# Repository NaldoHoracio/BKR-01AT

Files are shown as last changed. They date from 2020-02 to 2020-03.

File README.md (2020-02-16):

# Projeto Final da Disciplina de Circuitos Impressos
## BKR-01AT

"Eu gostaria que fosse desenvolvido um equipamento que fosse capaz de medir as vibrações e a temperatura de um gerador em funcionamento. Vou chamá-lo de BKR:01AT. Acredito que, a partir dos dados obtidos, poderemos tirar algumas conclusões que podem aumentar o tempo de vida útil do equipamento. O equipamento deve enviar as leituras para uma central a qual já está pronta se comunica com os sensores em uma rede mesh."

Os equipamentos selecionados para desenvolver esse equipamento são:
- Acelerômetro: LIS2DHTR;
- MCU + Bluetooth: nRF52832-QFAB;
- LED indicativo de sistema ligado (livre escolha, cor verde)
- LED indicativo de problema de vibração detectado (livre escolha, cor vermelha)
- LED indicativo de problema de temperatura detectado (livre escolha, cor vermelha)
- Botão de reset (livre escolha, baixo custo)
- Botão de função 1 (livre escolha, baixo custo)
- Botão de função 2 (livre escolha, baixo custo)
- Alimentação por bateria CR2032 de 3,0V (não precisa comprar, mas precisa ter os furos para soldar a pilha)
- Outros componentes necessários são de livre escolha inclusive a antena;

Restrições:
1. A placa deve ter componentes de apenas um lado;
2. A logomarca da empresa deve aparecer na camada Silk na parte de baixo da placa (onde não tem componentes)
3. A placa tem que ter o formato quadrado nas dimensões 60x60mm
4. A placa deve ter furos de montagem nas quinas superior esquerda e inferior direito com diâmetro de 3,2mm e o centro do furo deve estar a 5mm das duas bordas;
5. A placa será montada por equipamentos automáticos portanto deve conter dois fiduciais posicionados na maior distância possível entre eles na placa;
6. O nome do projeto deve estar presente na parte frontal da placa acompanhado com a versão P1;
7. As bordas a placa devem ser arredondadas;
8. O resistores utilizados devem ser 0402;
9. O equipamento deve ter interface de gravação TC2030;
10. As trilhas de alimentação devem ter 12mil de espessuras e as de sinal 6mil;
11. O Clearence da placa deve ser de 6mil;
12. A trilha da antena deve ser calculada utilizando coplanar wave guide para obter uma impedância de 50 ohms;
13. A trilha deve ser protegida com um shielding por todo o seu comprimento e deve ser cercada por um plano de ground com stitching aplicado a ele.

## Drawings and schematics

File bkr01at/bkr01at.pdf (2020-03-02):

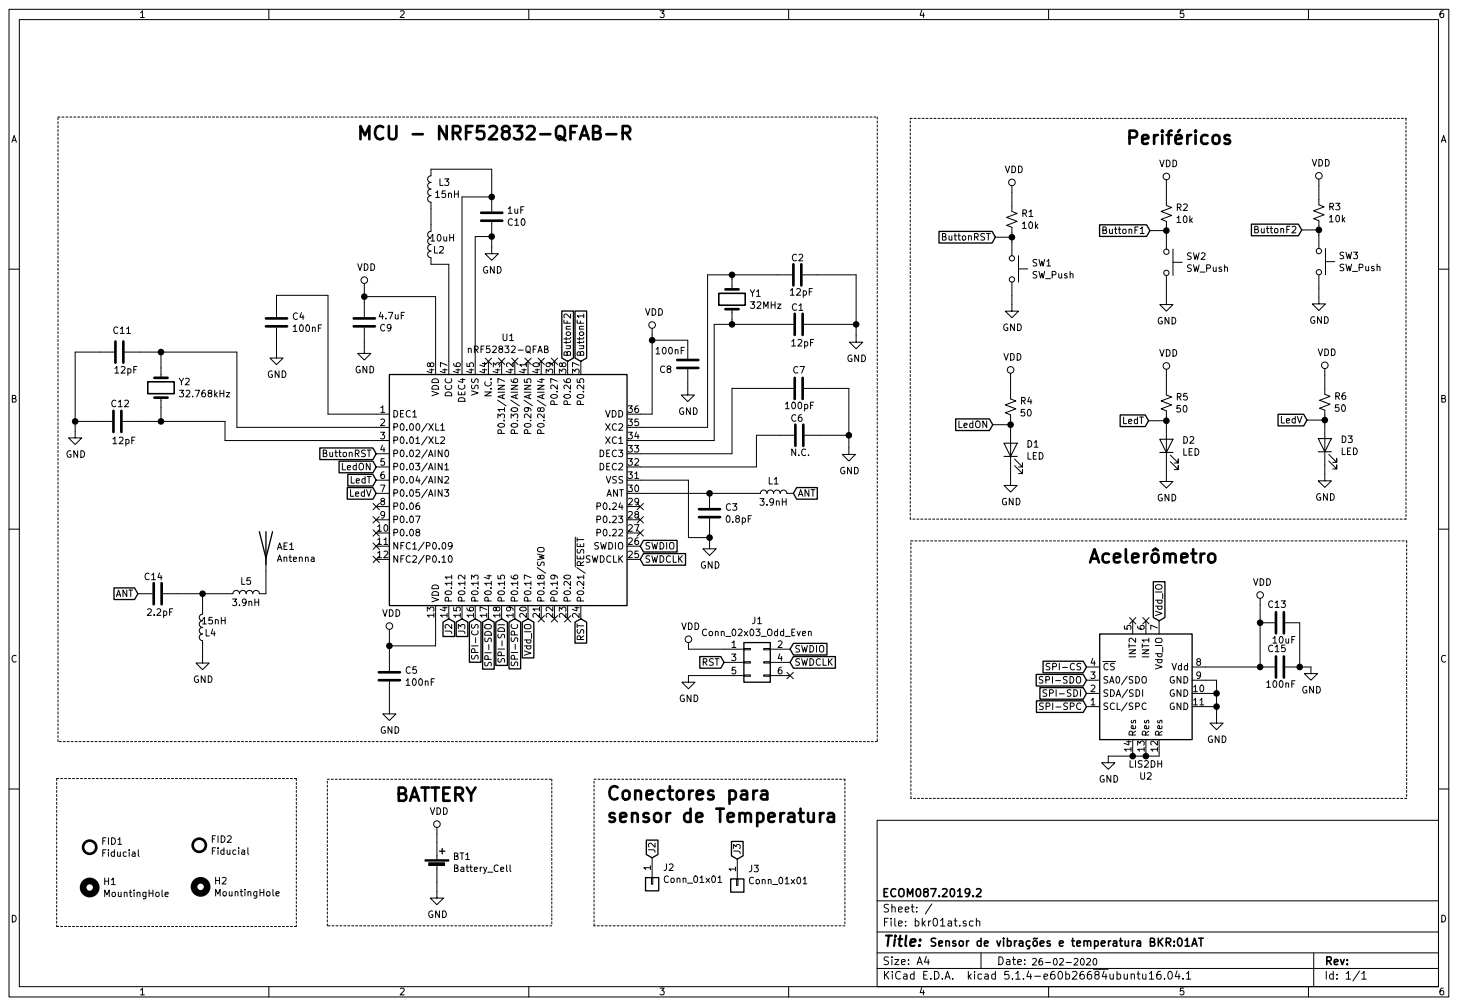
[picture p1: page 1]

SPI-SDI SPI-SDO

ECOM087.2019.2
Id: 1/1 Title: File: bkr01at.sch Sheet: /

Sensor de vibrações e temperatura BKR:01AT

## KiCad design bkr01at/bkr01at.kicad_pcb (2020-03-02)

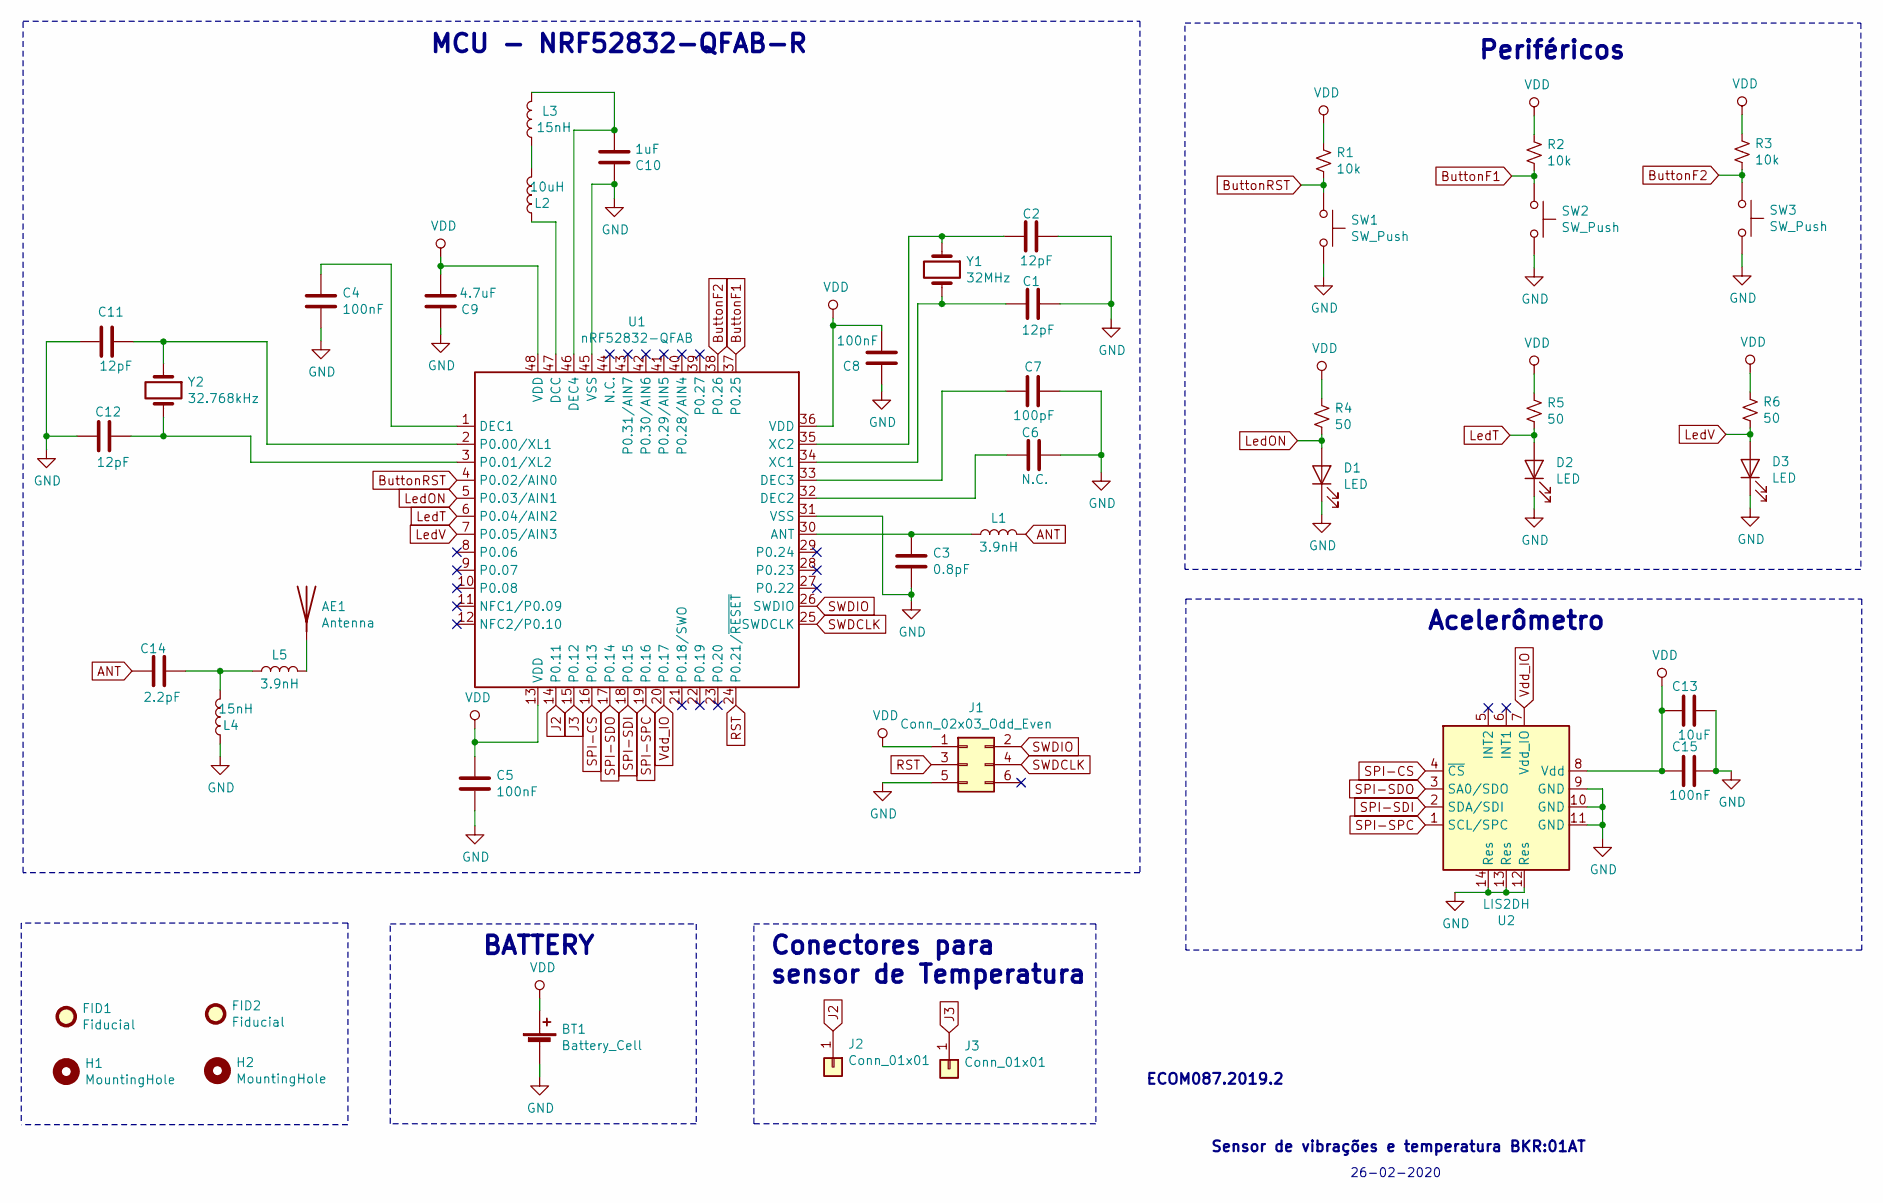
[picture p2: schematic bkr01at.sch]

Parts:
AE1: Antenna; 2450AT18B100
BT1: Battery_Cell; Battery_Panasonic_CR2032-VS1N_Vertical_CircularHoles
C1, C2, C11, C12: 12pF; C_0402_1005Metric
C3: 0.8pF; C_0402_1005Metric
C4, C5, C8, C15: 100nF; C_0402_1005Metric
C6: N.C.; C_0402_1005Metric
C7: 100pF; C_0402_1005Metric
C9: 4.7uF; C_0402_1005Metric
C10: 1uF; C_0402_1005Metric
C13: 10uF; C_0402_1005Metric
C14: 2.2pF; C_0402_1005Metric
D1, D2, D3: LED; LED_0603_1608Metric
FID1, FID2: Fiducial; Fiducial_0.5mm_Mask1.5mm
H1, H2: MountingHole; MountingHole_3.2mm_M3
J1: Conn_02x03_Odd_Even; Tag-Connect_TC2030-IDC-NL_2x03_P1.27mm_Vertical
J2, J3: Conn_01x01; SolderWirePad_1x01_Drill0.8mm
L1, L5: 3.9nH; L_0402_1005Metric
L2: 10uH; L_0402_1005Metric
L3, L4: 15nH; L_0402_1005Metric
R1, R2, R3: 10k; R_0402_1005Metric
R4, R5, R6: 50; R_0402_1005Metric
SW1, SW2, SW3: SW_Push; SW_MEC_5GSH9
U1: nRF52832-QFAB; QFN-48-1EP_6x6mm_P0.4mm_EP4.6x4.6mm
U2: LIS2DH; LGA-14_2x2mm_P0.35mm_LayoutBorder3x4y
Y1: 32MHz; Crystal_SMD_2016-4Pin_2.0x1.6mm
Y2: 32.768kHz; Crystal_SMD_3215-2Pin_3.2x1.5mm

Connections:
ANT: C14.1, L1.2
ButtonF1: R2.2, SW2.1, U1.37 (P0.25)
ButtonF2: R3.2, SW3.1, U1.38 (P0.26)
ButtonRST: R1.2, SW1.1, U1.4 (P0.02/AIN0)
GND: BT1.2 (-), C1.2, C2.2, C3.2, C4.2, C5.2, C6.2, C7.2, C8.1, C9.1, C10.1, C11.2, C12.2, C13.2, C15.2, D1.1 (K), D2.1 (K), D3.1 (K), J1.5, L4.1, SW1.2, SW2.2, SW3.2, U1.31 (VSS), U1.45 (VSS), U2.9 (GND), U2.10 (GND), U2.11 (GND), U2.12 (Res), U2.13 (Res), U2.14 (Res)
J2: J2.1, U1.14 (P0.11)
J3: J3.1, U1.15 (P0.12)
LedON: D1.2 (A), R4.2, U1.5 (P0.03/AIN1)
LedT: D2.2 (A), R5.2, U1.6 (P0.04/AIN2)
LedV: D3.2 (A), R6.2, U1.7 (P0.05/AIN3)
unnamed: AE1.1, L5.2
unnamed: C1.1, U1.34 (XC1), Y1.2
unnamed: C2.1, U1.35 (XC2), Y1.1
unnamed: C3.1, L1.1, U1.30 (ANT)
unnamed: C4.1, U1.1 (DEC1)
unnamed: C6.1, U1.32 (DEC2)
unnamed: C7.1, U1.33 (DEC3)
unnamed: C10.2, L3.2, U1.46 (DEC4)
unnamed: C11.1, U1.2 (P0.00/XL1), Y2.1
unnamed: C12.1, U1.3 (P0.01/XL2), Y2.2
unnamed: C14.2, L4.2, L5.1
unnamed: L2.1, U1.47 (DCC)
unnamed: L2.2, L3.1
RST: J1.3, U1.24 (P0.21/~RESET)
SPI-CS: U1.16 (P0.13), U2.4 (~CS)
SPI-SDI: U1.18 (P0.15), U2.2 (SDA/SDI)
SPI-SDO: U1.17 (P0.14), U2.3 (SA0/SDO)
SPI-SPC: U1.19 (P0.16), U2.1 (SCL/SPC)
SWDCLK: J1.4, U1.25 (SWDCLK)
SWDIO: J1.2, U1.26 (SWDIO)
VDD: BT1.1 (+), C5.1, C8.2, C9.2, C13.1, C15.1, J1.1, R1.1, R2.1, R3.1, R4.1, R5.1, R6.1, U1.13 (VDD), U1.36 (VDD), U1.48 (VDD), U2.8 (Vdd)
Vdd_IO: U1.20 (P0.17), U2.7 (Vdd_IO)

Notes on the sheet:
Sensor de vibrações e temperatura BKR:01AT
ECOM087.2019.2
26-02-2020
MCU - NRF52832-QFAB-R
Periféricos
Acelerômetro
BATTERY
Conectores para sensor de Temperatura

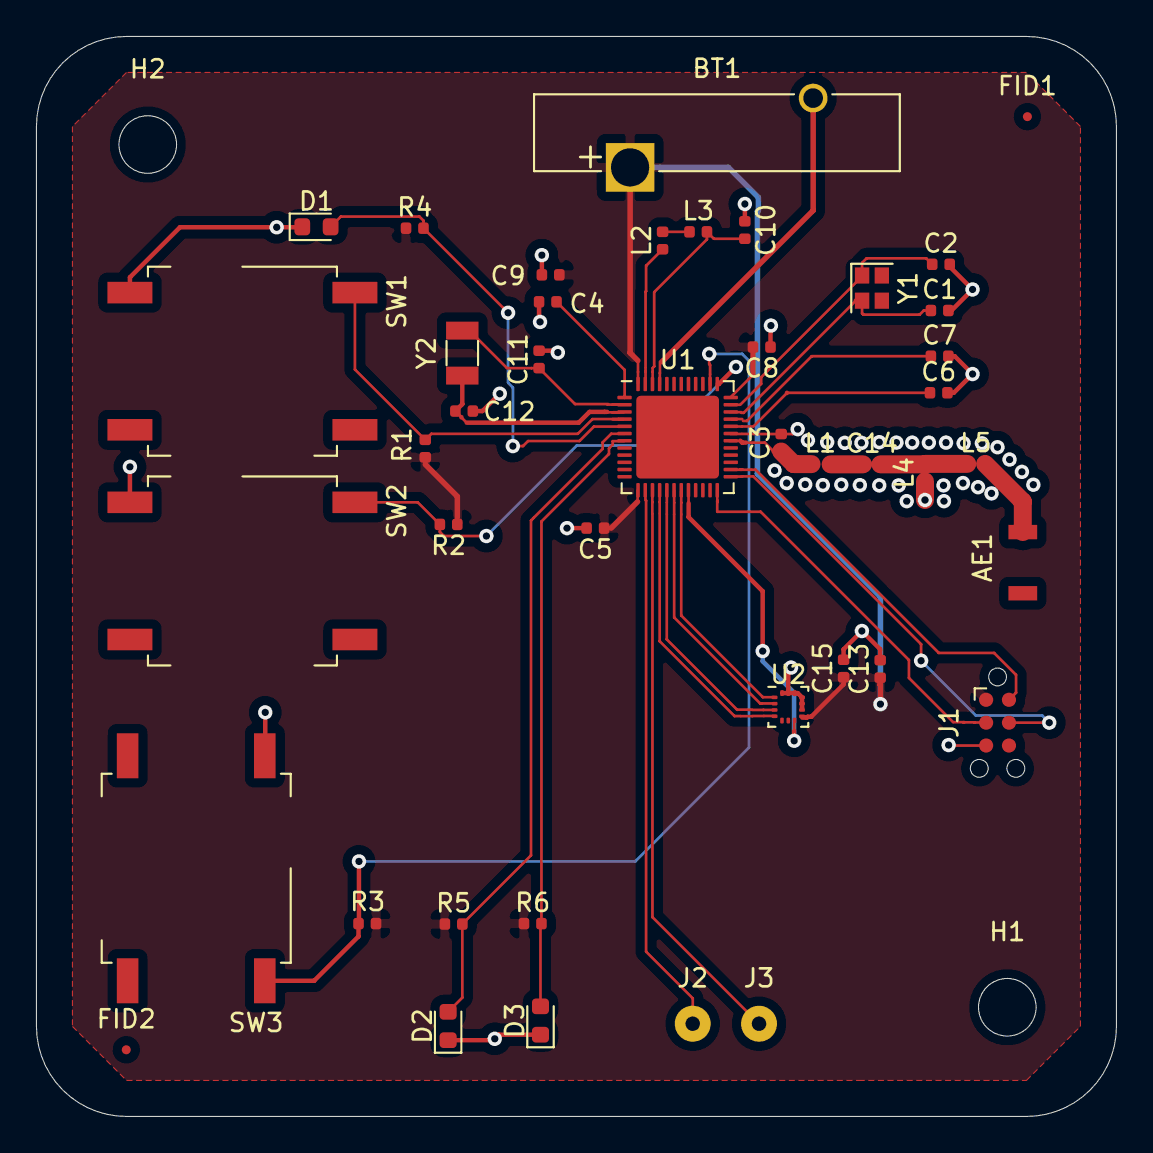
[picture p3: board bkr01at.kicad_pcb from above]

Board: 2 copper layers, 60.0 x 60.0 mm, 45 parts (0 on the bottom side), 32 nets.

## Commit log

2020-02-27 Atualizando esquemático. Referências alocadas.
    [bkr01at.kicad_pcb, bkr01at.sch]
2020-02-28 Finalizando esquemático. Começando PCB.
    [bkr01at.sch]
2020-03-01 Atualizando esquemático.
    [bkr01at.sch]
2020-03-02 Esquemático ok. PCB is loading.
    [bkr01at.sch]
2020-03-02 Finalizando PCB.
    [bkr01at.kicad_pcb, bkr01at.sch]
2020-03-02 PCB e Esquemático finalizados.
    [bkr01at.kicad_pcb]
